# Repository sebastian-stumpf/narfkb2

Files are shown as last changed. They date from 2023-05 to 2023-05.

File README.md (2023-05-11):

# narfkb2

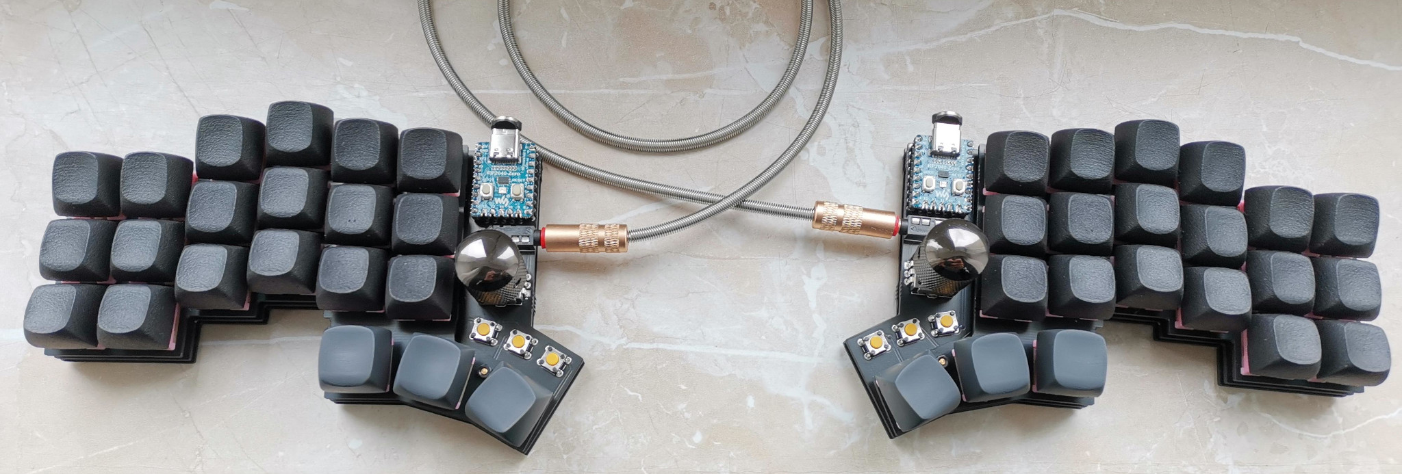
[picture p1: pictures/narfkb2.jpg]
narfkb2


More pictures in the `pictures` directory.

## Attention

I'm a hobbyist/amateur at best. So there may be things that aren't optimized. That being said I've had the files
in the `gerbers/` directory manufactured at JLC with 1.6mm size and they work just fine with my fork of the qmk repository
directory. So if you decide to use this, then please be advised that I'm not providing any sort of liability and you should
exercise some caution.

## BOM

| Quantity  | Item | Comment |
| --- | --- | --- |
| 2 | Waveshare RP2040-Zero | |
| 2 | IC-Sockets for MCU | Optional but recommended |
| 2 | TRRS Sockets | |
| 50 | 1N4148 SOD123 diodes | |
| 42 | MX Hotswap Sockets | |
| 2 | EC11 Encoders | |
| 6 | Omrom 6mm Tact switches | B3F-1002 |
| 42 | MX Switches + Keycaps | |
| 12 | M2 Screws, Nuts, Bolts and Spacers | |

## Firmware

See [my fork](https://github.com/sebastian-stumpf/qmk_firmware/tree/sepp/keyboards/narfkb2) of the qmk repository. Nothing special here.
You can just copy the code over to your own repository.

## Feedback

I'm always happy to hear your opinions about this and if you decide to build this board then please do send me a picture of it.

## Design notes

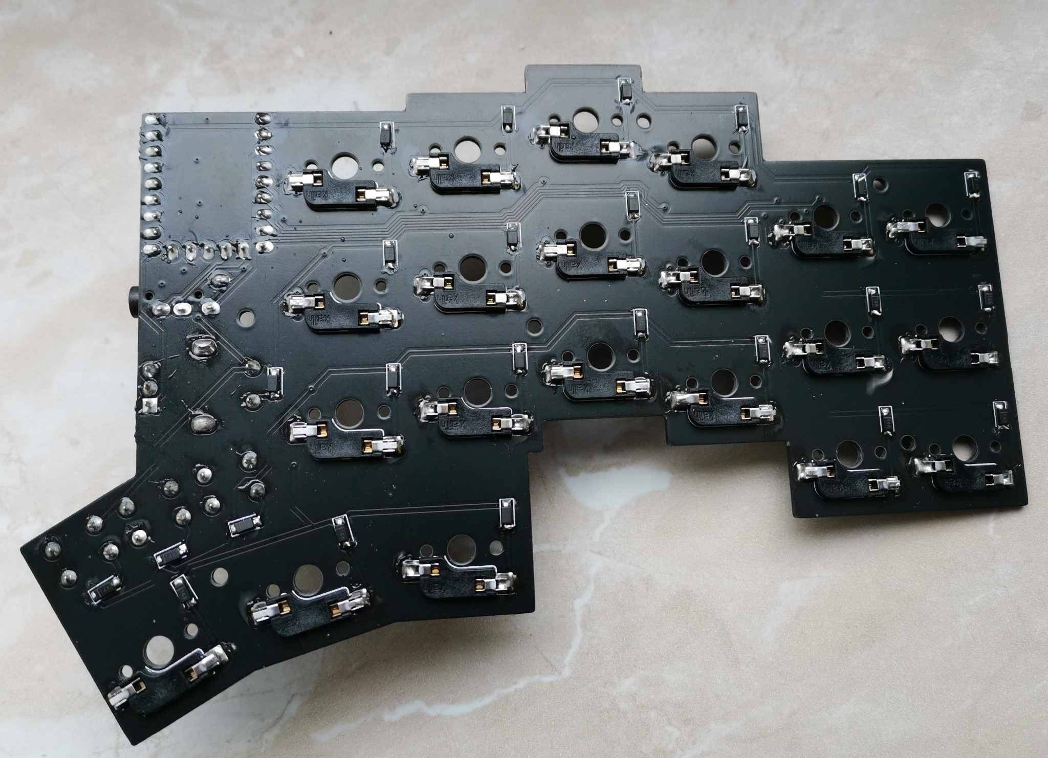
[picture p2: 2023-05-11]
pictures/back.jpg

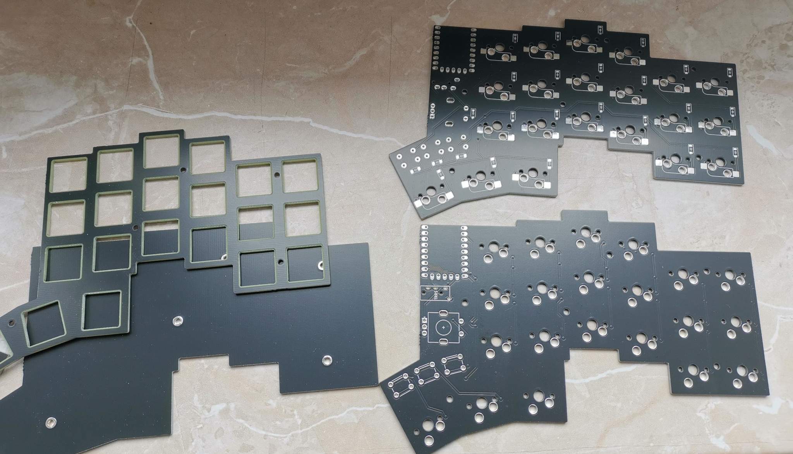
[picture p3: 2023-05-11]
pictures/pcbs.jpg

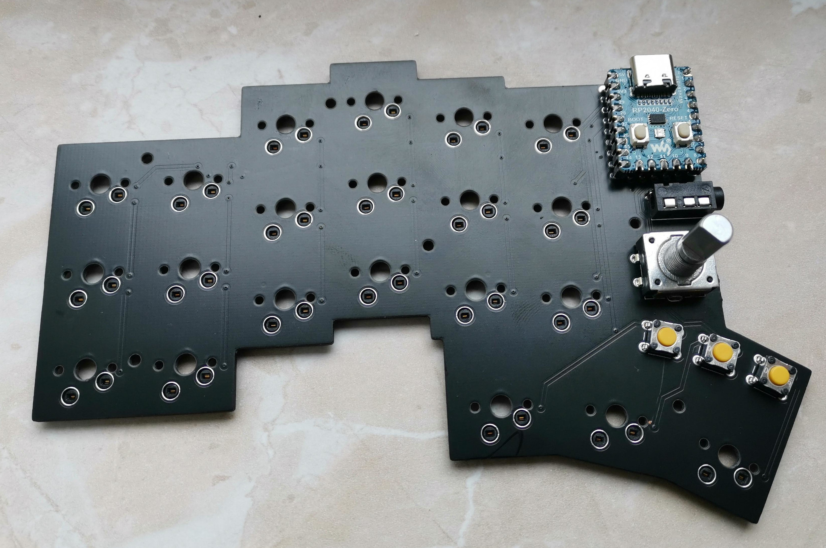
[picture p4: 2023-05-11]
pictures/front.jpg

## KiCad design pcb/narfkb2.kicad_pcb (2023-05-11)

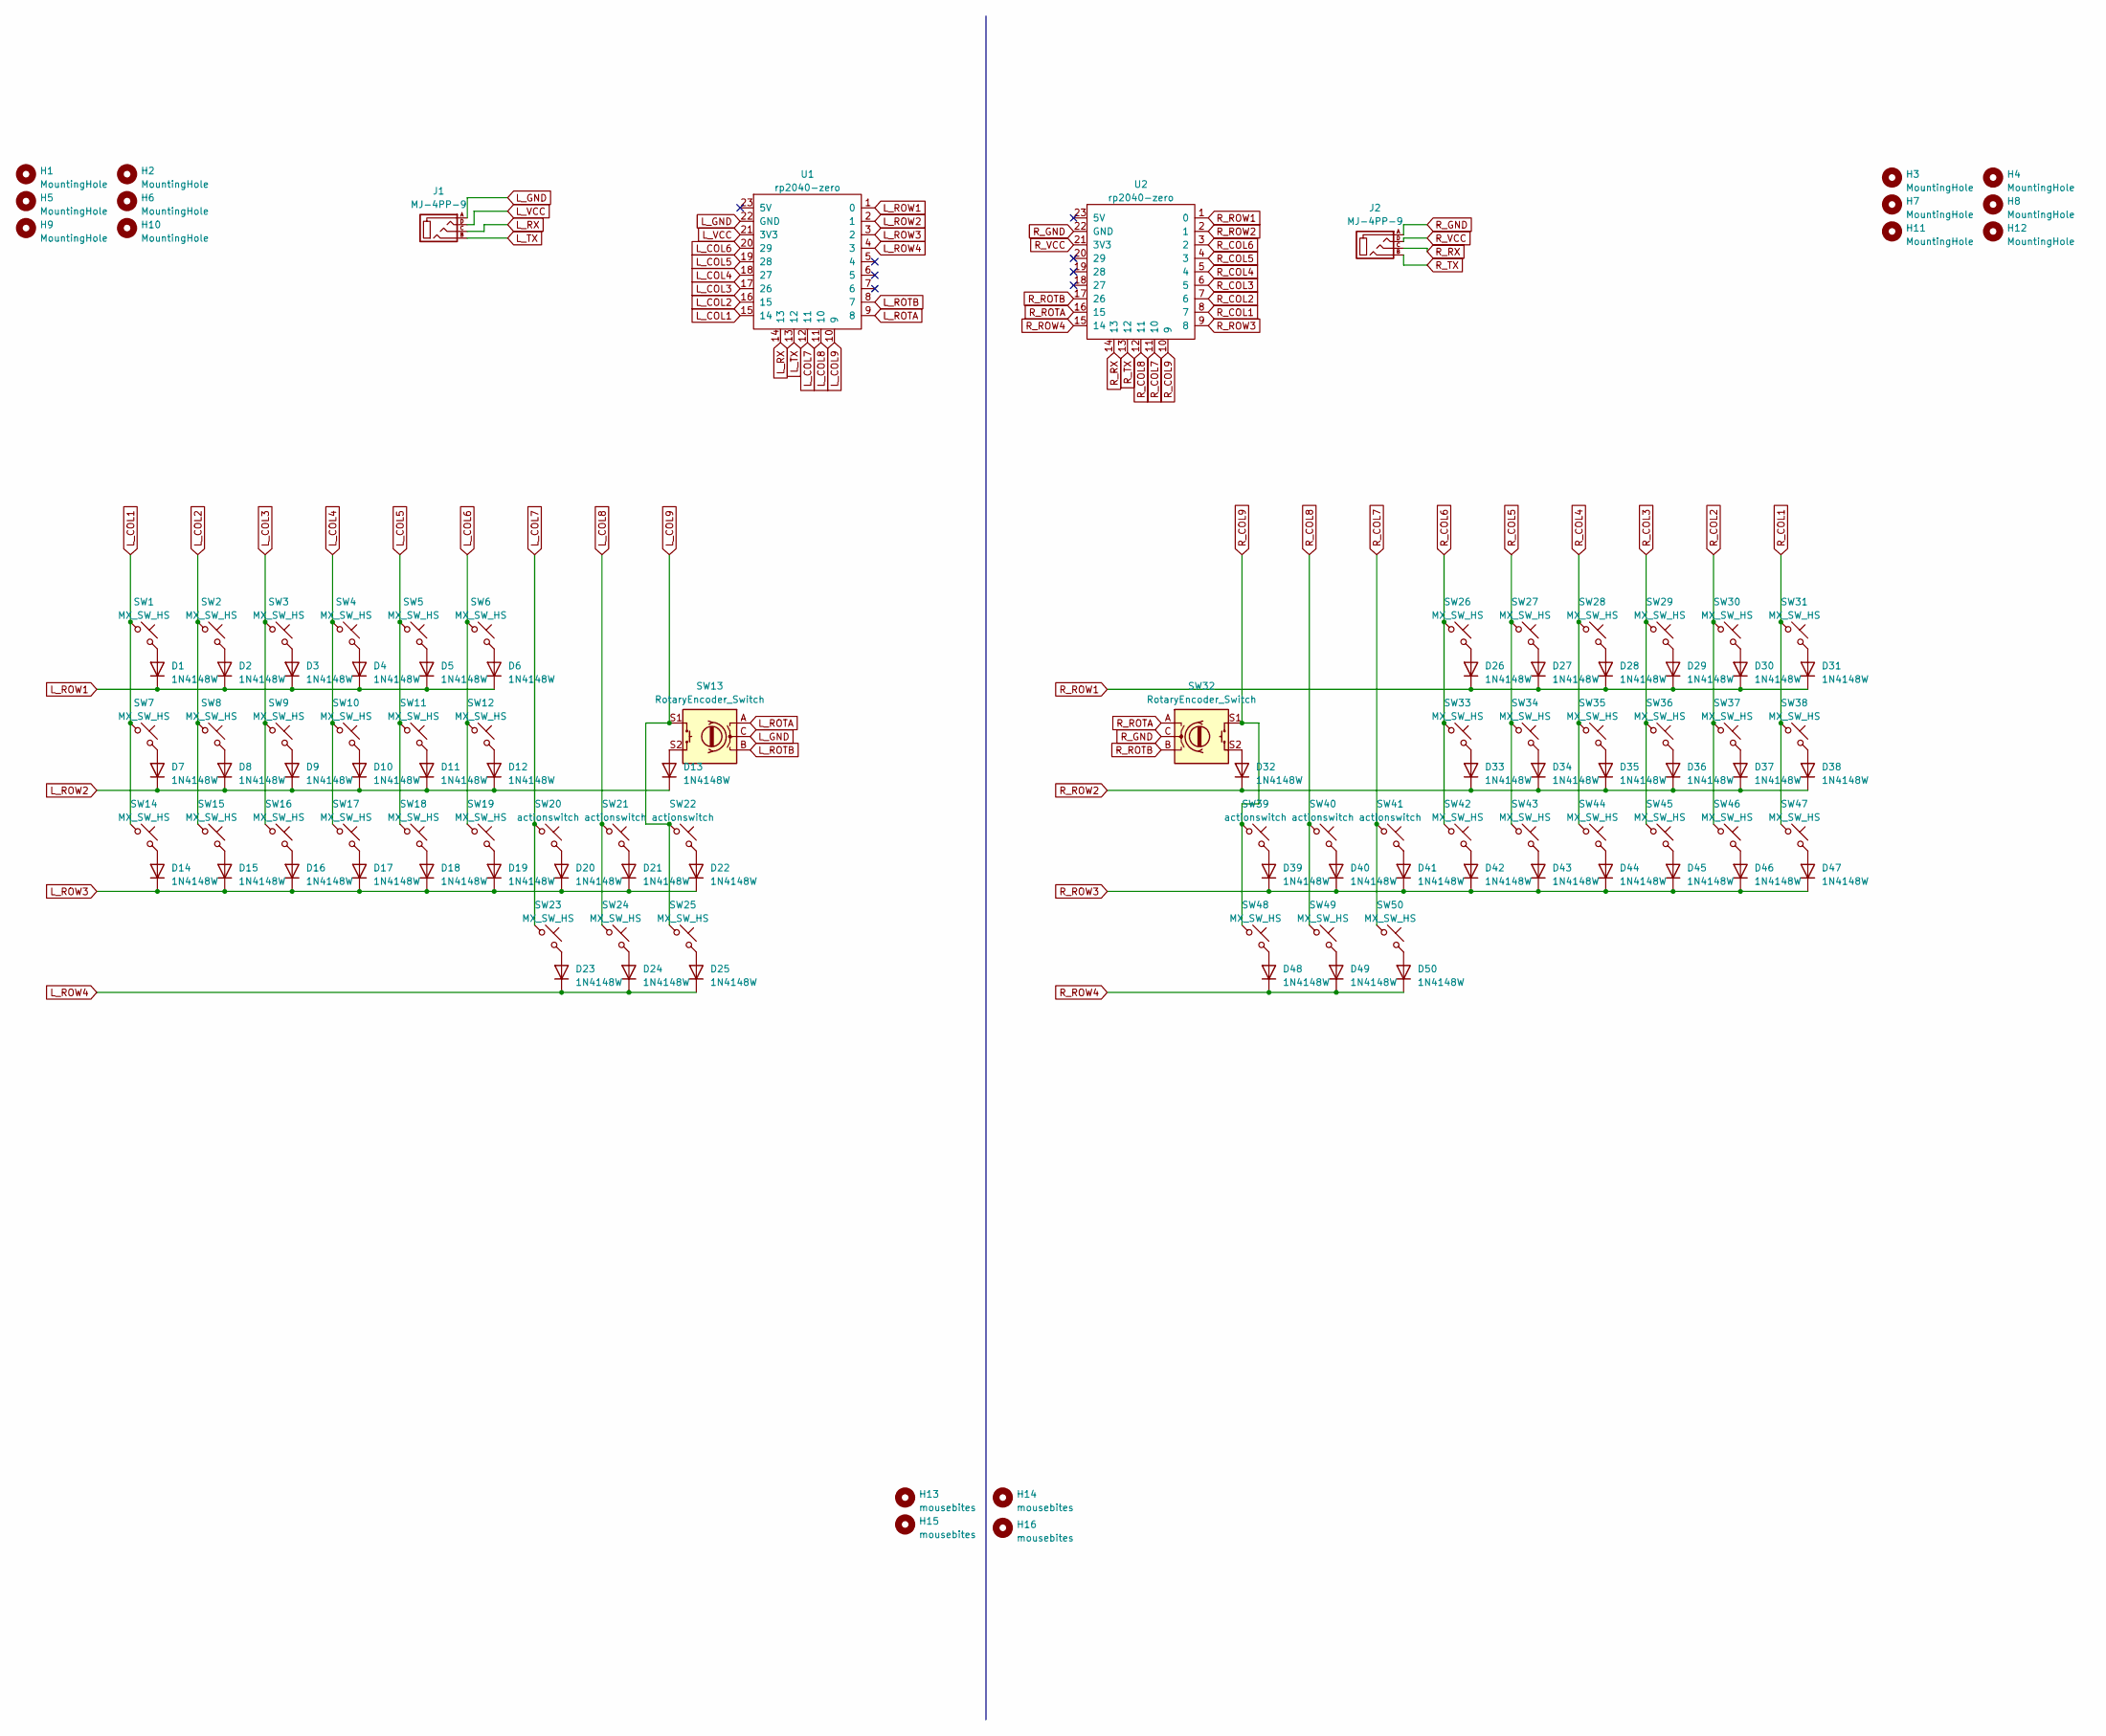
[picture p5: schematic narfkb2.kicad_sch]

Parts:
D1, D2, D3, D4, D5, D6, D7, D8, D9, D10, D11, D12, D13, D14, D15, D16, D17, D18, D19, D20, D21, D22, D23, D24, D25, D26, D27, D28, D29, D30, D31, D32, D33, D34, D35, D36, D37, D38, D39, D40, D41, D42, D43, D44, D45, D46, D47, D48, D49, D50: 1N4148W; D_SOD-123
H1, H2, H3, H4, H5, H6, H7, H8, H9, H10, H11, H12: MountingHole; MountingHole_2.2mm_M2_DIN965
H13, H14, H15, H16: mousebites; breakaway-mousebites
J1, J2: MJ-4PP-9
SW1, SW2, SW3, SW4, SW5, SW6, SW7, SW8, SW9, SW10, SW11, SW12, SW14, SW15, SW16, SW17, SW18, SW19, SW23, SW24, SW25, SW26, SW27, SW28, SW29, SW30, SW31, SW33, SW34, SW35, SW36, SW37, SW38, SW42, SW43, SW44, SW45, SW46, SW47, SW48, SW49, SW50: MX_SW_HS; SW_MX_HS_1u
SW13, SW32: RotaryEncoder_Switch; RotaryEncoder_EC11
SW20, SW21, SW22, SW39, SW40, SW41: actionswitch
U1, U2: rp2040-zero; rp2040-zero-tht

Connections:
L_COL1: SW1.1, SW7.1, SW14.1, U1.15 (14)
L_COL2: SW2.1, SW8.1, SW15.1, U1.16 (15)
L_COL3: SW3.1, SW9.1, SW16.1, U1.17 (26)
L_COL4: SW4.1, SW10.1, SW17.1, U1.18 (27)
L_COL5: SW5.1, SW11.1, SW18.1, U1.19 (28)
L_COL6: SW6.1, SW12.1, SW19.1, U1.20 (29)
L_COL7: SW20.1, SW23.1, U1.12 (11)
L_COL8: SW21.1, SW24.1, U1.11 (10)
L_COL9: SW13.S1, SW22.1, SW25.1, U1.10 (9)
L_GND: J1.A, SW13.C, U1.22 (GND)
L_ROTA: SW13.A, U1.9 (8)
L_ROTB: SW13.B, U1.8 (7)
L_ROW1: D1.1 (K), D2.1 (K), D3.1 (K), D4.1 (K), D5.1 (K), D6.1 (K), U1.1 (0)
L_ROW2: D7.1 (K), D8.1 (K), D9.1 (K), D10.1 (K), D11.1 (K), D12.1 (K), D13.1 (K), U1.2 (1)
L_ROW3: D14.1 (K), D15.1 (K), D16.1 (K), D17.1 (K), D18.1 (K), D19.1 (K), D20.1 (K), D21.1 (K), D22.1 (K), U1.3 (2)
L_ROW4: D23.1 (K), D24.1 (K), D25.1 (K), U1.4 (3)
L_RX: J1.C, U1.14 (13)
L_TX: J1.B, U1.13 (12)
L_VCC: J1.D, U1.21 (3V3)
unnamed: D1.2 (A), SW1.2
unnamed: D2.2 (A), SW2.2
unnamed: D3.2 (A), SW3.2
unnamed: D4.2 (A), SW4.2
unnamed: D5.2 (A), SW5.2
unnamed: D6.2 (A), SW6.2
unnamed: D7.2 (A), SW7.2
unnamed: D8.2 (A), SW8.2
unnamed: D9.2 (A), SW9.2
unnamed: D10.2 (A), SW10.2
unnamed: D11.2 (A), SW11.2
unnamed: D12.2 (A), SW12.2
unnamed: D13.2 (A), SW13.S2
unnamed: D14.2 (A), SW14.2
unnamed: D15.2 (A), SW15.2
unnamed: D16.2 (A), SW16.2
unnamed: D17.2 (A), SW17.2
unnamed: D18.2 (A), SW18.2
unnamed: D19.2 (A), SW19.2
unnamed: D20.2 (A), SW20.2
unnamed: D21.2 (A), SW21.2
unnamed: D22.2 (A), SW22.2
unnamed: D23.2 (A), SW23.2
unnamed: D24.2 (A), SW24.2
unnamed: D25.2 (A), SW25.2
unnamed: D26.2 (A), SW26.2
unnamed: D27.2 (A), SW27.2
unnamed: D28.2 (A), SW28.2
unnamed: D29.2 (A), SW29.2
unnamed: D30.2 (A), SW30.2
unnamed: D31.2 (A), SW31.2
unnamed: D32.2 (A), SW32.S2
unnamed: D33.2 (A), SW33.2
unnamed: D34.2 (A), SW34.2
unnamed: D35.2 (A), SW35.2
unnamed: D36.2 (A), SW36.2
unnamed: D37.2 (A), SW37.2
unnamed: D38.2 (A), SW38.2
unnamed: D39.2 (A), SW39.2
unnamed: D40.2 (A), SW40.2
unnamed: D41.2 (A), SW41.2
unnamed: D42.2 (A), SW42.2
unnamed: D43.2 (A), SW43.2
unnamed: D44.2 (A), SW44.2
unnamed: D45.2 (A), SW45.2
unnamed: D46.2 (A), SW46.2
unnamed: D47.2 (A), SW47.2
unnamed: D48.2 (A), SW48.2
unnamed: D49.2 (A), SW49.2
unnamed: D50.2 (A), SW50.2
R_COL1: SW31.1, SW38.1, SW47.1, U2.8 (7)
R_COL2: SW30.1, SW37.1, SW46.1, U2.7 (6)
R_COL3: SW29.1, SW36.1, SW45.1, U2.6 (5)
R_COL4: SW28.1, SW35.1, SW44.1, U2.5 (4)
R_COL5: SW27.1, SW34.1, SW43.1, U2.4 (3)
R_COL6: SW26.1, SW33.1, SW42.1, U2.3 (2)
R_COL7: SW41.1, SW50.1, U2.11 (10)
R_COL8: SW40.1, SW49.1, U2.12 (11)
R_COL9: SW32.S1, SW39.1, SW48.1, U2.10 (9)
R_GND: J2.A, SW32.C, U2.22 (GND)
R_ROTA: SW32.A, U2.16 (15)
R_ROTB: SW32.B, U2.17 (26)
R_ROW1: D26.1 (K), D27.1 (K), D28.1 (K), D29.1 (K), D30.1 (K), D31.1 (K), U2.1 (0)
R_ROW2: D32.1 (K), D33.1 (K), D34.1 (K), D35.1 (K), D36.1 (K), D37.1 (K), D38.1 (K), U2.2 (1)
R_ROW3: D39.1 (K), D40.1 (K), D41.1 (K), D42.1 (K), D43.1 (K), D44.1 (K), D45.1 (K), D46.1 (K), D47.1 (K), U2.9 (8)
R_ROW4: D48.1 (K), D49.1 (K), D50.1 (K), U2.15 (14)
R_RX: J2.C, U2.14 (13)
R_TX: J2.B, U2.13 (12)
R_VCC: J2.D, U2.21 (3V3)

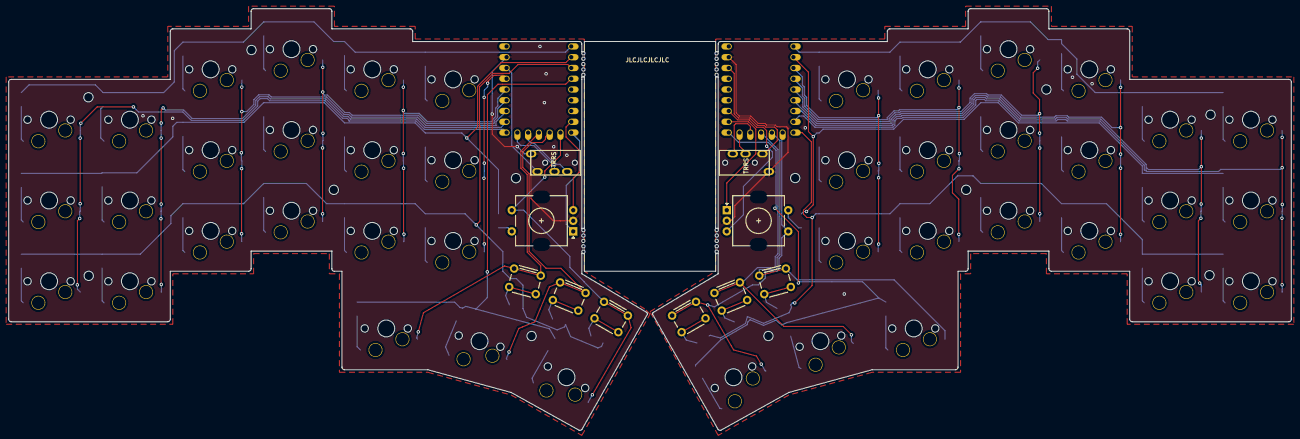
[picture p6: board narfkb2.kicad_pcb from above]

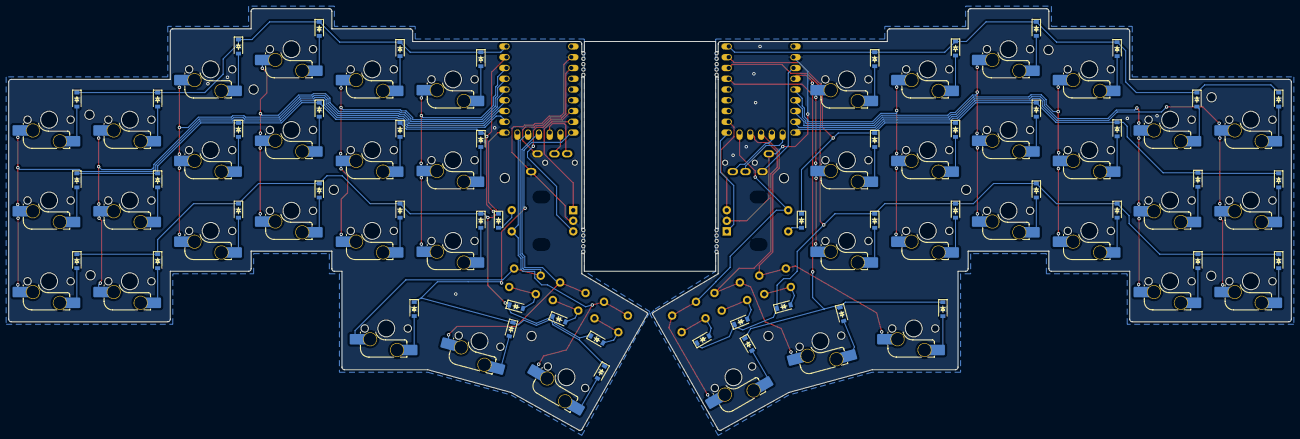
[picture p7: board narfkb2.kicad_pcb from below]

Board: 2 copper layers, 302.4 x 99.4 mm, 120 parts (50 on the bottom side), 88 nets.
